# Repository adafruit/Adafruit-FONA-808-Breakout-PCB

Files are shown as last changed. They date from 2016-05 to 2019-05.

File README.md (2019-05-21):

## Adafruit FONA 808 Breakout PCB
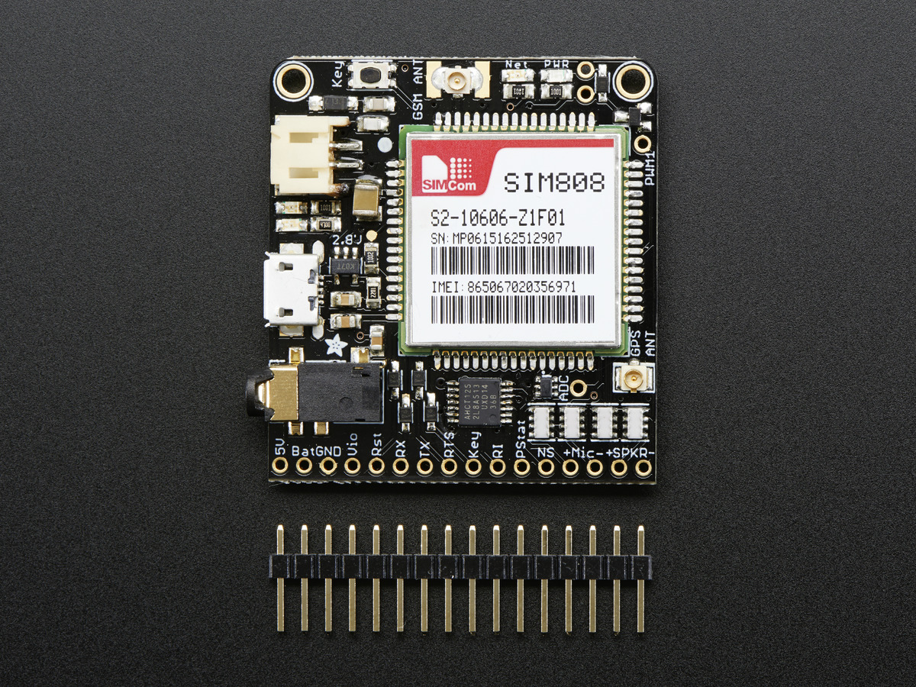
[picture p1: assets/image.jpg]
<a href="http://www.adafruit.com/products/2542"><br/>
Click here to purchase one from the Adafruit shop</a>

Cellular + GPS tracking, all in one? Oh yes! Introducing Adafruit FONA 808 MiniGSM + GPS, an all-in-one cellular phone module with that lets you add location-tracking, voice, text, SMS and data to your project in an adorable little package. (It does not contain a drum machine, tho)

This module measures only 1.75"x1.6" but packs a surprising amount of technology into it's little frame. At the heart is a powerful GSM cellular module (we use the latest SIM808) with integrated GPS. This module can do just about everything.

PCB files for the Adafruit FONA 808 Breakout. The format is EagleCAD schematic and board layout
 https://www.adafruit.com/products/2542 

### License

Adafruit invests time and resources providing this open source design, please support Adafruit and open-source hardware by purchasing products from [Adafruit](https://www.adafruit.com)!

All text above must be included in any redistribution

Designed by Limor Fried/Ladyada for Adafruit Industries.
Creative Commons Attribution/Share-Alike, all text above must be included in any redistribution. 
See license.txt for additional information.

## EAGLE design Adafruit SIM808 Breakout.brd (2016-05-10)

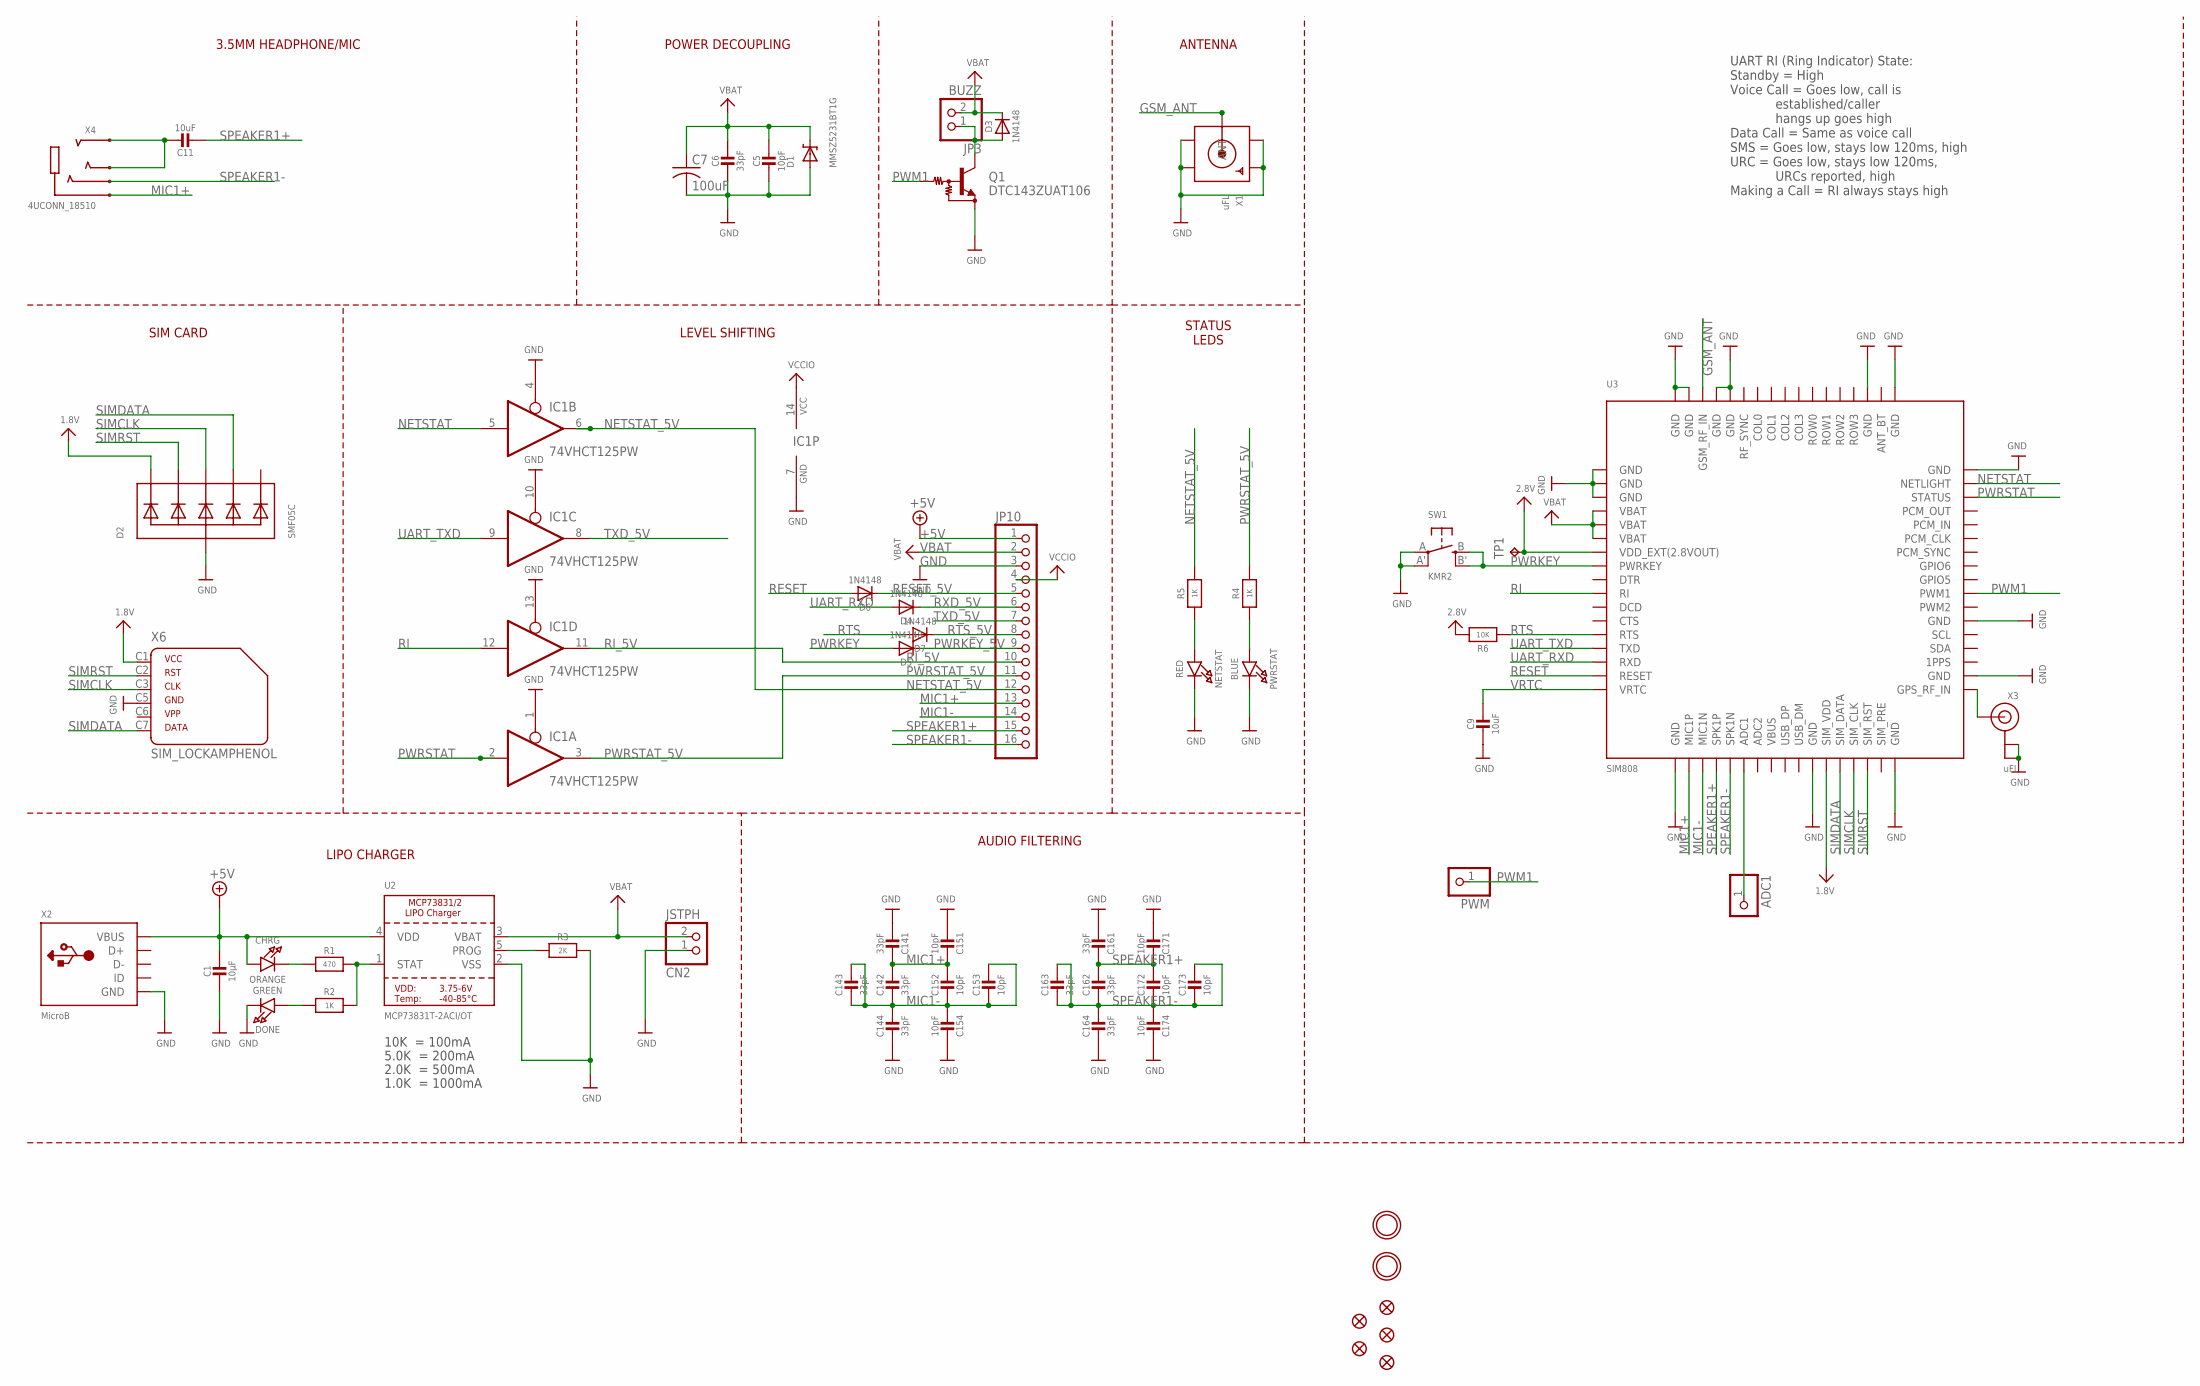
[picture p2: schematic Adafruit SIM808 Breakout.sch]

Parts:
ADC1: PINHD-1X1CB; 1X01-CLEANBIG
C1: 10µF; 0805-NO
C5: 10pF; 0805-NO
C6: 33pF; 0805-NO
C7: 100uF; C1210
C9, C11: 10uF; 0805-NO
C14, C16: 33pF; RESPACK_4X0603
C15, C17: 10pF; RESPACK_4X0603
CHRG: ORANGE; CHIPLED_0805_NOOUTLINE
CN2: JSTPH; JSTPH2
D1: MMSZ5231BT1G; SOD-123
D2: SMF05C; SOT363
D3, D4, D5, D6, D7: 1N4148; SOD-323
DONE: GREEN; CHIPLED_0805_NOOUTLINE
FID1, FID2, FID3, FID4, FID5: FIDUCIAL""; FIDUCIAL_1MM
IC1: 74VHCT125PW; TSSOP14
JP3: BUZZ; 1X02_ROUND
JP10: HEADER-1X16ROUND; 1X16_ROUND
NETSTAT: RED; CHIPLED_0805_NOOUTLINE
PWM: PINHD-1X1CB; 1X01-CLEANBIG
PWRSTAT: BLUE; CHIPLED_0805_NOOUTLINE
Q1: DTC143ZUAT106; SC59-BEC
R1: 470; 0805-NO
R2, R4, R5: 1K; 0805-NO
R3: 2K; 0805-NO
R6: 10K; 0805-NO
SW1: KMR2; BTN_KMR2_4.6X2.8
TP1: TPTP11R; TP11R
U2: MCP73831T-2ACI/OT; SOT23-5
U3: SIM808; SIM900_SMT
U$33, U$34: MOUNTINGHOLE2.5; MOUNTINGHOLE_2.5_PLATED
X1: uFL; SMA_EDGELAUNCH_UFL
X2: MicroB; 4UCONN_20329
X3: uFL; U.FL
X4: 4UCONN_18510
X6: SIM_LOCKAMPHENOL; C707_10M006_512_2

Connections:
1.8V: D2.1 (C1), U3.P$29 (SIM_VDD), X6.C1 (1)
2.8V: R6.2, TP1.TP, U3.P$7 (VDD_EXT(2.8VOUT))
+5V: C1.1, CHRG.A, JP10.1, U2.4 (VDD), X2.VBUS
GND: C1.2, C5.2, C6.2, C7.2, C9.2, C14.5 (2), C14.8 (2), C15.4 (1), C15.8 (2), C16.5 (2), C16.8 (2), C17.4 (1), C17.8 (2), CN2.1, D1.A, D2.2 (A), DONE.C, IC1.1 (OE), IC1.4 (OE), IC1.7 (GND), IC1.10 (OE), IC1.13 (OE), JP10.3, NETSTAT.C, PWRSTAT.C, Q1.E, R3.2, SW1.A, SW1.A' (P1), U2.2 (VSS), U3.P$1 (GND), U3.P$2 (GND), U3.P$3 (GND), U3.P$18 (GND), U3.P$28 (GND), U3.P$34 (GND), U3.P$36 (GND), U3.P$40 (GND), U3.P$51 (GND), U3.P$52 (GND), U3.P$54 (GND), U3.P$64 (GND), U3.P$65 (GND), U3.P$67 (GND), U3.P$68 (GND), X1.GND@1 (GND1), X1.GND@2 (GND2), X1.GND@3 (GND3), X1.GND@4 (GND4), X2.BASE@1 (GND), X2.BASE@2 (GND), X2.GND, X2.SPRT@1 (GND), X2.SPRT@2 (GND), X2.SPRT@3 (GND), X2.SPRT@4 (GND), X3.1 (GND), X3.2 (GND), X6.C5 (4)
GSM_ANT: U3.P$66 (GSM_RF_IN), X1.P (ANT)
HP+: C11.1, X4.2-TIP (RING3), X4.3-OUTER_SLEEVE (RING2)
MIC1+: C14.1, C14.2 (1), C15.1, C15.2 (1), JP10.13, U3.P$19 (MIC1P), X4.1-GND (TIP)
MIC1-: C14.3 (1), C14.4 (1), C14.6 (2), C14.7 (2), C15.3 (1), C15.5 (2), C15.6 (2), C15.7 (2), JP10.14, U3.P$20 (MIC1N)
unnamed: CHRG.C, R1.1
unnamed: R1.2, R2.2, U2.1 (STAT)
unnamed: U3.P$35 (GPS_RF_IN), X3.3 (SIGNAL)
unnamed: PWRSTAT.A, R4.1
unnamed: R3.1, U2.5 (PROG)
unnamed: DONE.A, R2.1
unnamed: ADC1.1, U3.P$23 (ADC1)
unnamed: NETSTAT.A, R5.1
unnamed: D3.A, JP3.1, Q1.C
NETSTAT: IC1.5 (I), U3.P$50 (NETLIGHT)
NETSTAT_5V: IC1.6 (O), JP10.12, R5.2
PWM1: PWM.1, Q1.B, U3.P$42 (PWM1)
PWRKEY: D5.A, SW1.B (S), SW1.B' (S1), U3.P$8 (PWRKEY)
PWRKEY_5V: D5.C, JP10.9
PWRSTAT: IC1.2 (I), U3.P$49 (STATUS)
PWRSTAT_5V: IC1.3 (O), JP10.11, R4.2
RESET: D6.A, U3.P$16 (RESET)
RESET_5V: D6.C, JP10.5
RI: IC1.12 (I), U3.P$10 (RI)
RI_5V: IC1.11 (O), JP10.10
RTS: D7.A, R6.1, U3.P$13 (RTS)
RTS_5V: D7.C, JP10.8
RXD_5V: D4.C, JP10.6
SIMCLK: D2.4 (C3), U3.P$31 (SIM_CLK), X6.C3 (3)
SIMDATA: D2.5 (C4), U3.P$30 (SIM_DATA), X6.C7 (6)
SIMRST: D2.3 (C2), U3.P$32 (SIM_RST), X6.C2 (2)
SPEAKER1+: C11.2, C16.1, C16.2 (1), C17.1, C17.2 (1), JP10.15, U3.P$21 (SPK1P)
SPEAKER1-: C16.3 (1), C16.4 (1), C16.6 (2), C16.7 (2), C17.3 (1), C17.5 (2), C17.6 (2), C17.7 (2), JP10.16, U3.P$22 (SPK1N), X4.4-INNER_SLEEVE (RING1)
TXD_5V: IC1.8 (O), JP10.7
UART_RXD: D4.A, U3.P$15 (RXD)
UART_TXD: IC1.9 (I), U3.P$14 (TXD)
VBAT: C5.1, C6.1, C7.1, CN2.2, D1.C, D3.C, JP3.2, JP10.2, U2.3 (VBAT), U3.P$4 (VBAT), U3.P$5 (VBAT), U3.P$6 (VBAT)
VBUS: U3.P$25 (VBUS)
VCCIO: IC1.14 (VCC), JP10.4
VRTC: C9.1, U3.P$17 (VRTC)

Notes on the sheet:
10K = 100mA
5.0K = 200mA
2.0K = 500mA
1.0K = 1000mA
UART RI (Ring Indicator) State: Standby = High Voice Call = Goes low, call is established/caller hangs up goes high Data Call = Same as voice call SMS = Goes low, stays low 120ms, high URC = Goes low, stays low 120ms, URCs reported, high Making a Call = RI always stays high
ANTENNA
POWER DECOUPLING
3.5MM HEADPHONE/MIC
SIM CARD
LEVEL SHIFTING
LIPO CHARGER
AUDIO FILTERING
STATUS LEDS

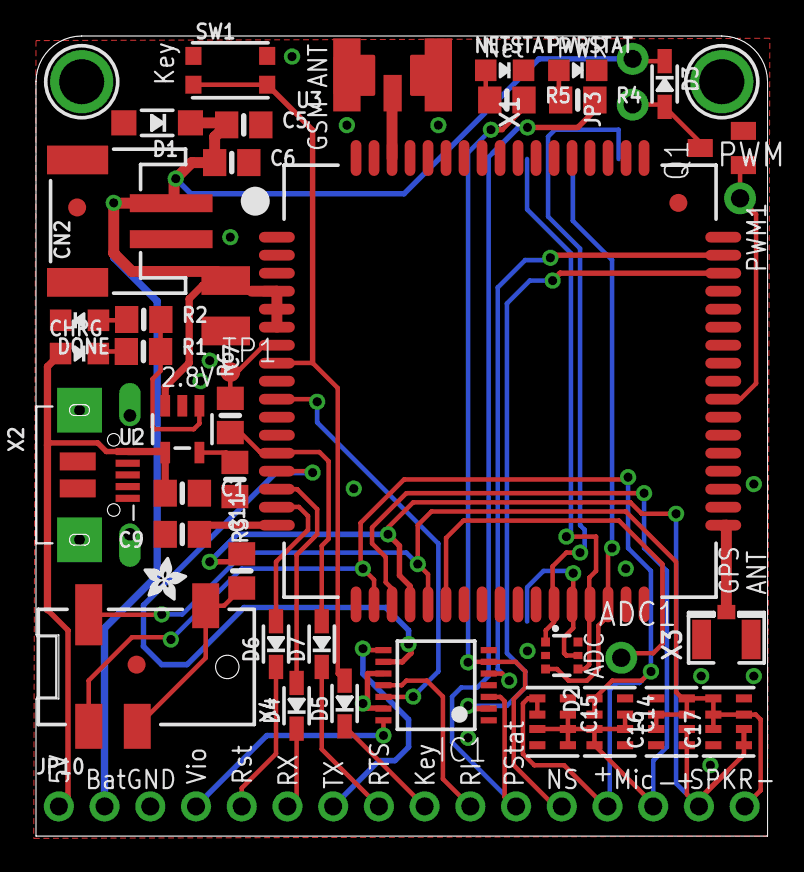
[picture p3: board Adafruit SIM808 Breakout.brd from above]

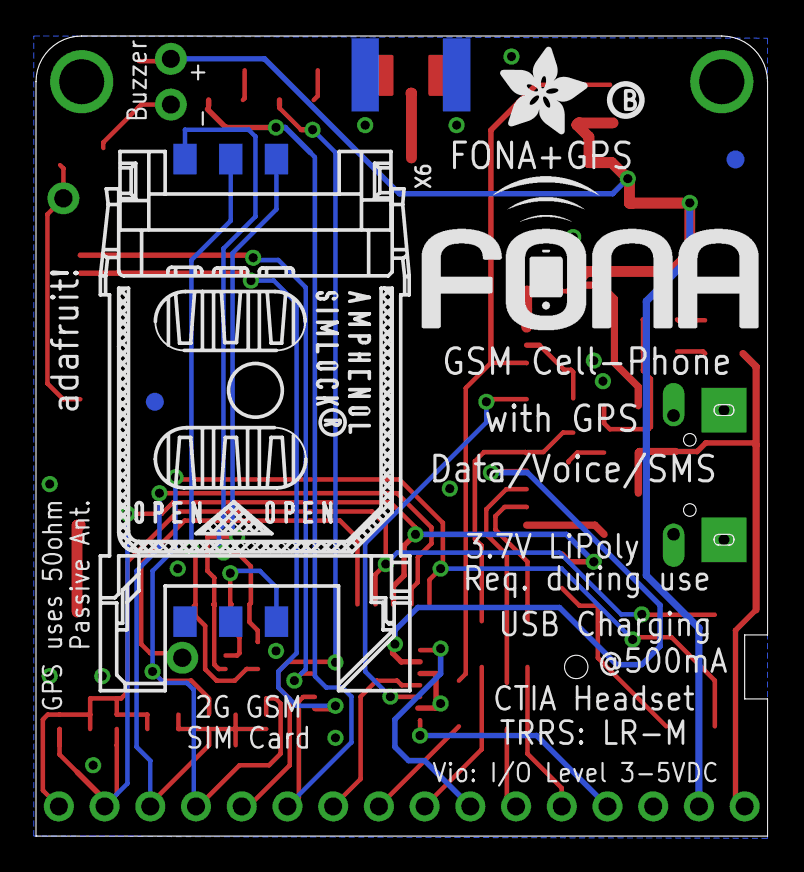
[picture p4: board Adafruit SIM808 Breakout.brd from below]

Board: 2 copper layers, 40.6 x 44.5 mm, 54 parts (6 on the bottom side), 42 nets.

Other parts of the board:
U$21: ADAFRUIT_2.5MM
U$25: PCBFEAT-REV-040
U$26: FONA_LOGO
U$36: ADAFRUIT_5MM

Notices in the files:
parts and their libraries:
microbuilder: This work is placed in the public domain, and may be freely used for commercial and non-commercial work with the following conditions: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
